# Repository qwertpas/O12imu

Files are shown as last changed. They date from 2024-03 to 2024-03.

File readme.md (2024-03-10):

## Compact 6DOF sensor fusion IMU for RS485 bus

Intended to work with [squirrelbrain](https://github.com/qwertpas/squirrelbrain) as part of the [Pintobotics](https://pintobotics.substack.com) project.

IMU: [LSM6DSV](https://www.st.com/en/mems-and-sensors/lsm6dsv.html)

MCU: [STM32L011F4U](https://www.digikey.com/en/products/detail/stmicroelectronics/STM32L011F4U6TR/6166960)

Size: 12.5mm x 12.5mm

Mounting: 4x M2 on 12mm diameter circle 

Connection: 2x 4pin 0.5mm pitch FFC for power and RS485 communication (daisy chainable)

Alternate connection: I2C and interrupt solder pads, aux GPIO/ADC

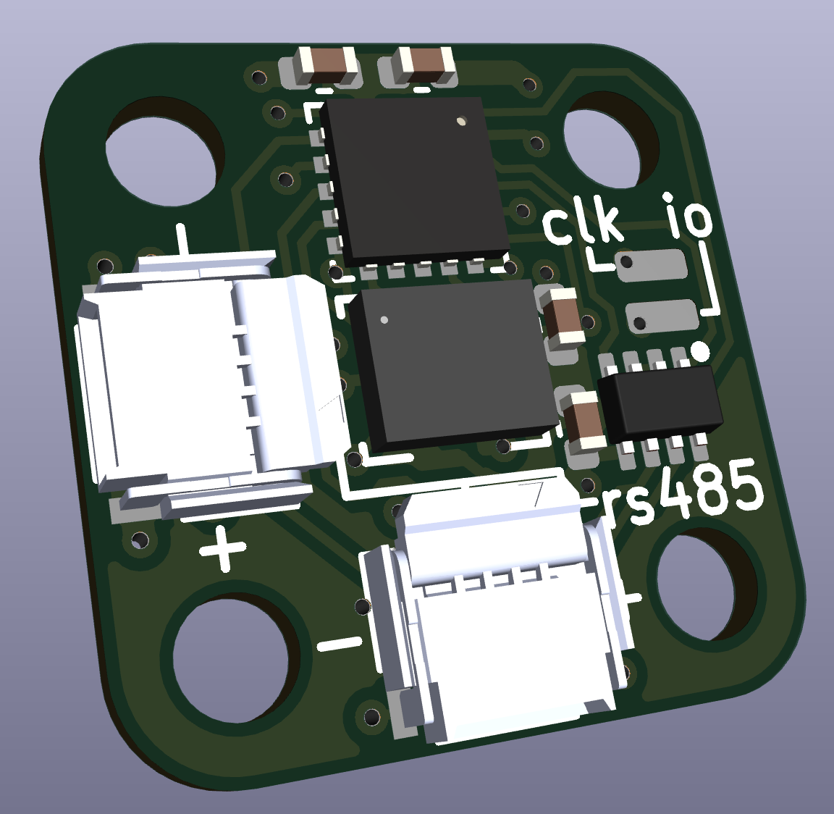
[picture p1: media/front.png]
Front View

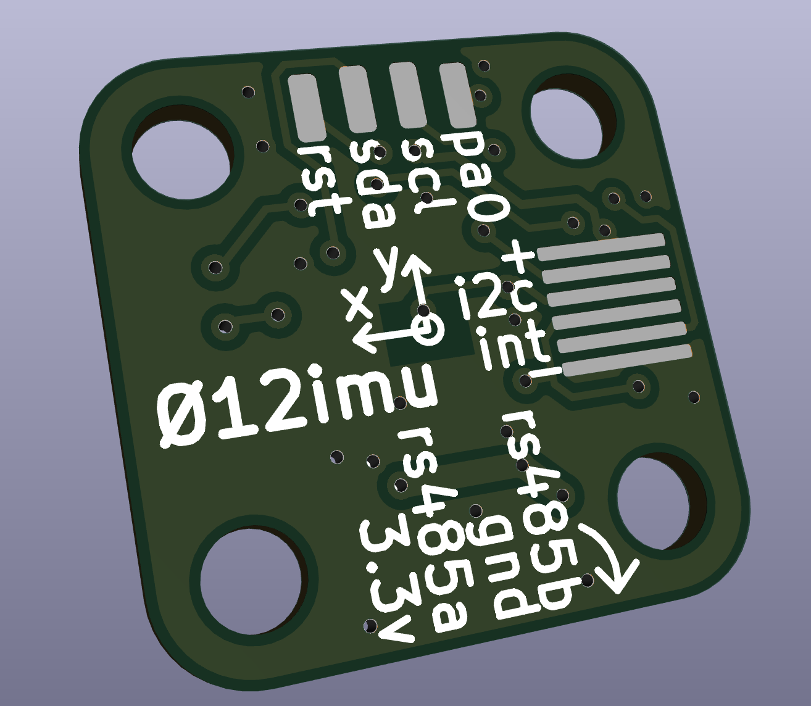
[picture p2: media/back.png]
Back View

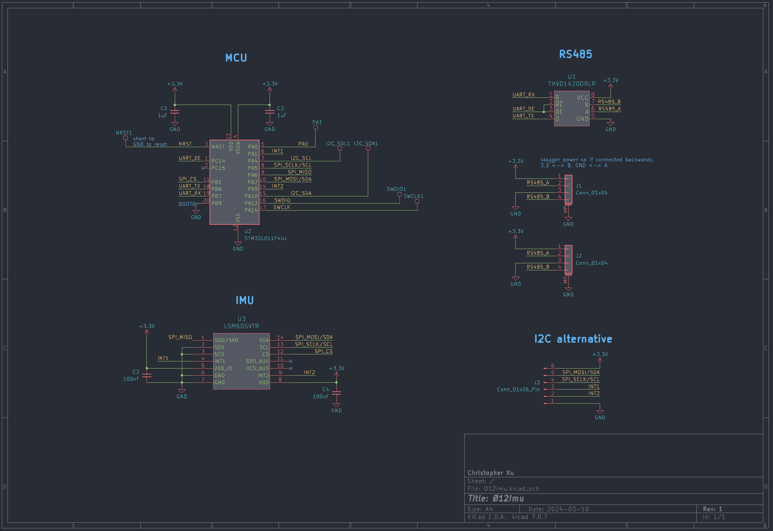
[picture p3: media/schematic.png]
schematic


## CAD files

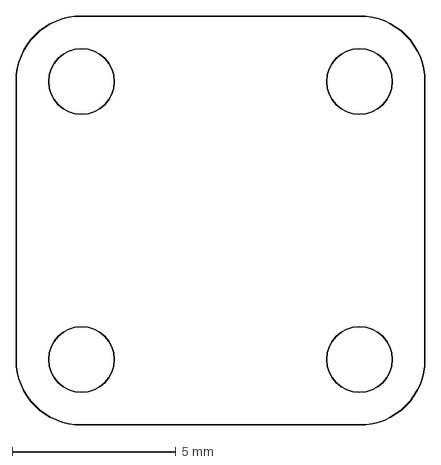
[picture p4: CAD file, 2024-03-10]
O12.dxf
12.5 x 12.5 mm

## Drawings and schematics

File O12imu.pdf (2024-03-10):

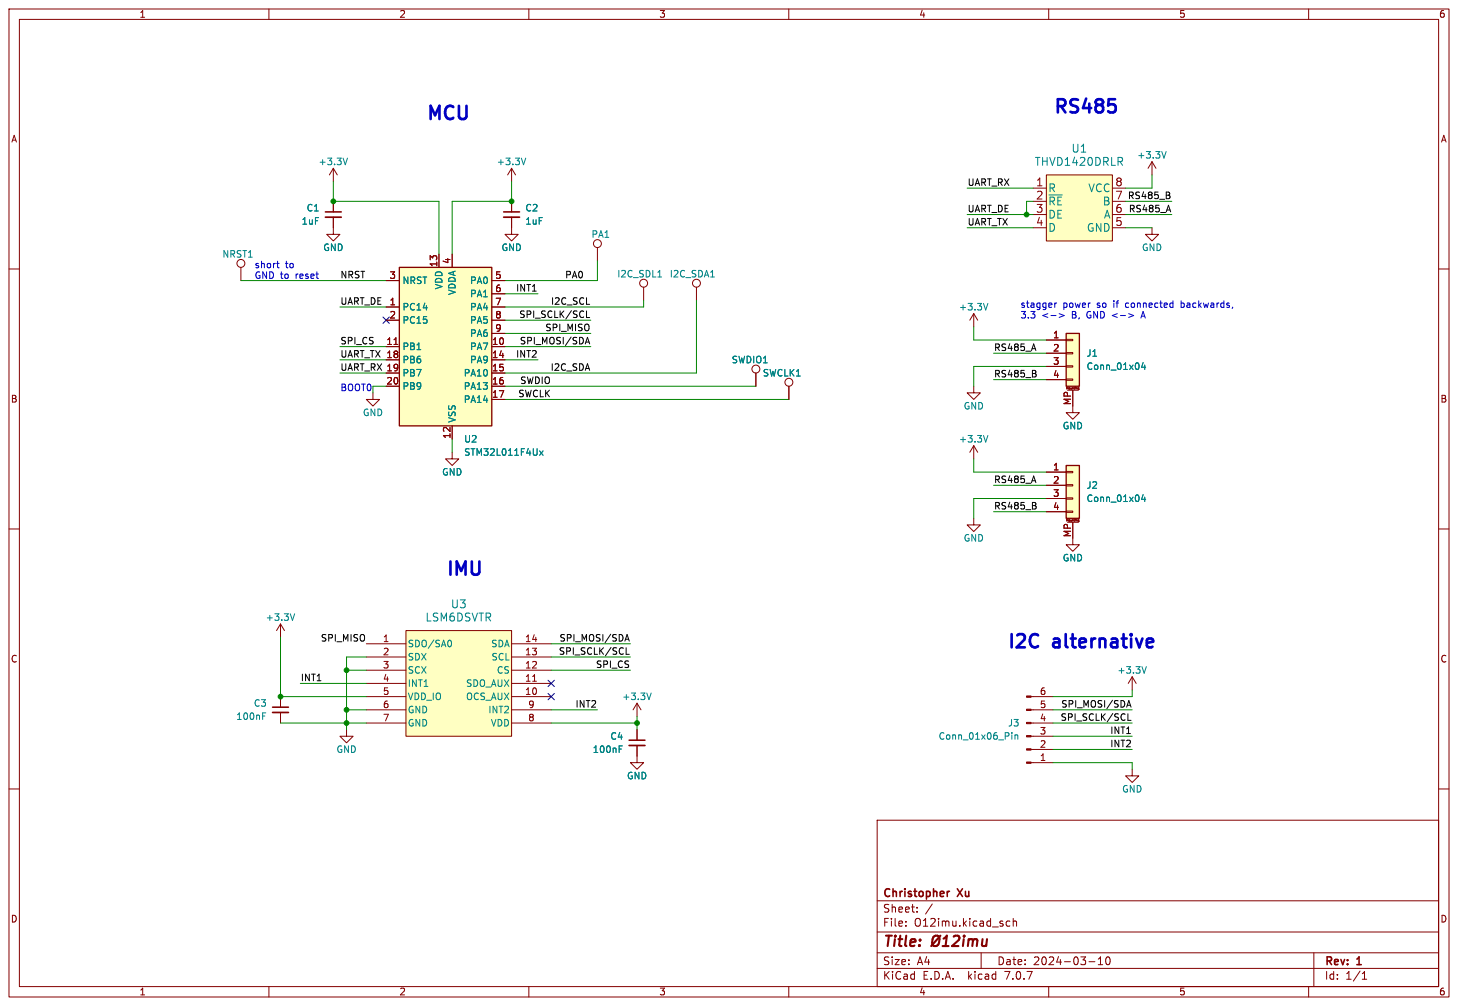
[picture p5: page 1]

File: O12imu.kicad_sch Sheet: / Christopher Xu

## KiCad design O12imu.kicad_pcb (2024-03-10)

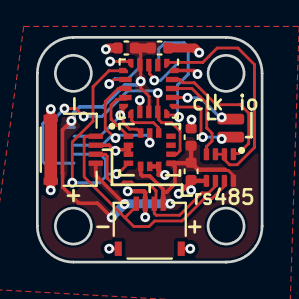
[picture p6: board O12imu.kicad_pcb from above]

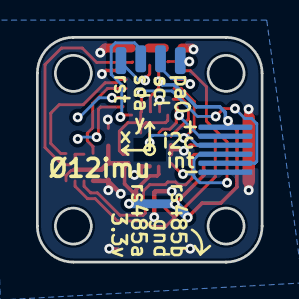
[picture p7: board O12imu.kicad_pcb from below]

Board: 2 copper layers, 12.5 x 12.5 mm, 16 parts (5 on the bottom side), 19 nets.

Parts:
C1, C2: 1uF; C_0402_1005Metric
C3, C4: 100nF; C_0402_1005Metric
I2C_SDA1, I2C_SDL1: TestPoint; TestPoint_Pad_Rect
J1, J2: Conn_01x04; TE_2328702-4
J3: Conn_01x06_Pin; FFC_0.5mm_6p
NRST1: TestPoint; TestPoint_Pad_Rect
PA1: TestPoint; TestPoint_Pad_Rect
SWCLK1: TestPoint; TestPoint_Pad_Rect
SWDIO1: TestPoint; TestPoint_Pad_Rect
U1: THVD1420DRLR; THVD1420DRLR_SOT-585
U2: STM32L011F4Ux; ST_UFQFPN-20_3x3mm_P0.5mm
U3: LSM6DSVTR; LGA14-L_2P59X3P1X0P5_STM

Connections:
+3.3V: C1.1, C2.1, C3.1, C4.1, J1.1, J2.1, J3.6, U1.8 (VCC), U2.4 (VDDA), U2.13 (VDD), U3.5 (VDD_IO), U3.8 (VDD)
/I2C_SCL: I2C_SDL1.1, U2.7 (PA4)
/I2C_SDA: I2C_SDA1.1, U2.15 (PA10)
/INT1: J3.3, U2.6 (PA1), U3.4 (INT1)
/INT2: J3.2, U2.14 (PA9), U3.9 (INT2)
/NRST: NRST1.1, U2.3 (NRST)
/PA0: PA1.1, U2.5 (PA0)
/RS485_A: J1.2, J2.2, U1.6 (A)
/RS485_B: J1.4, J2.4, U1.7 (B)
/SPI_CS: U2.11 (PB1), U3.12 (CS)
/SPI_MISO: U2.9 (PA6), U3.1 (SDO/SA0)
/SPI_MOSI/SDA: J3.5, U2.10 (PA7), U3.14 (SDA)
/SPI_SCLK/SCL: J3.4, U2.8 (PA5), U3.13 (SCL)
/SWCLK: SWCLK1.1, U2.17 (PA14)
/SWDIO: SWDIO1.1, U2.16 (PA13)
/UART_DE: U1.2 (~RE), U1.3 (DE), U2.1 (PC14)
/UART_RX: U1.1 (R), U2.19 (PB7)
/UART_TX: U1.4 (D), U2.18 (PB6)
GND: C1.2, C2.2, C3.2, C4.2, J1.3, J1.MP (MountPin), J2.3, J2.MP (MountPin), J3.1, U1.5 (GND), U2.12 (VSS), U2.20 (PB9), U3.2 (SDX), U3.3 (SCX), U3.6 (GND), U3.7 (GND)

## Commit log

2024-03-10 readme, bom, schematic pdf
    [O12imu-B_Cu.gbl, O12imu-B_Mask.gbs, O12imu-B_Paste.gbp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]
2024-03-10 shifted cap pos, readme details
    [O12imu-B_Cu.gbl, O12imu-B_Mask.gbs, O12imu-B_Paste.gbp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]
